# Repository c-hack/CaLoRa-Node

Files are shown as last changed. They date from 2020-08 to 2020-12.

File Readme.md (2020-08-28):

# CaLoRa-Node
## c-hack.de and surasto.de 2020 

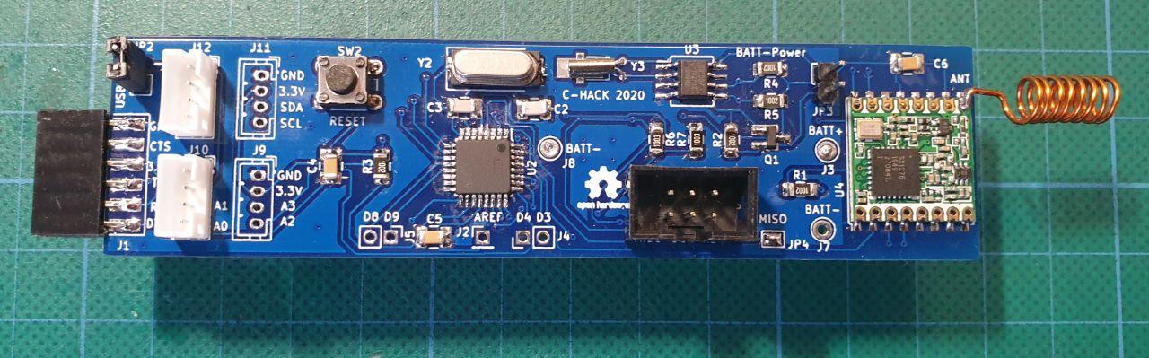
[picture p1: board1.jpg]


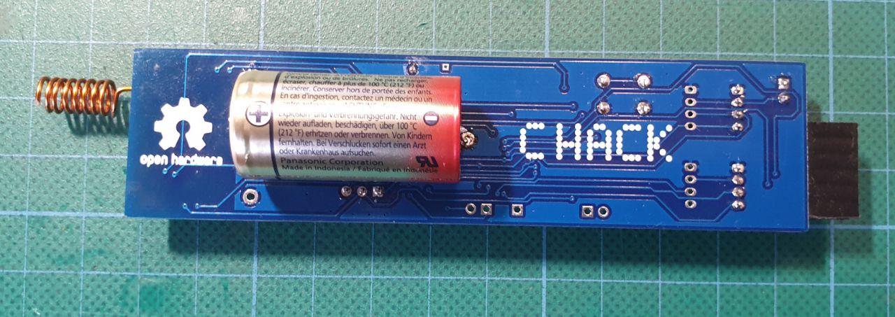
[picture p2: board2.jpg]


This LoRaWAN node is designed to run for long time on a battery.
It uses an external RTC (DS1337) with alarm function to enable or disable the complete power supply by switching a P-MOS FET.
This is the deepest sleep possible.

It uses an Atmel ATMega328 with the Arduino-UNO bootloader.
The LoRAWAN is implemented with an HopeRF RFM95W module.
The board implements some grove compatible connectors wuth I2C and analog inputs of the MCU.

We use the [lmic](https://github.com/matthijskooijman/arduino-lmic "lmic") software library for now but will add a wrapper to make it simpler.

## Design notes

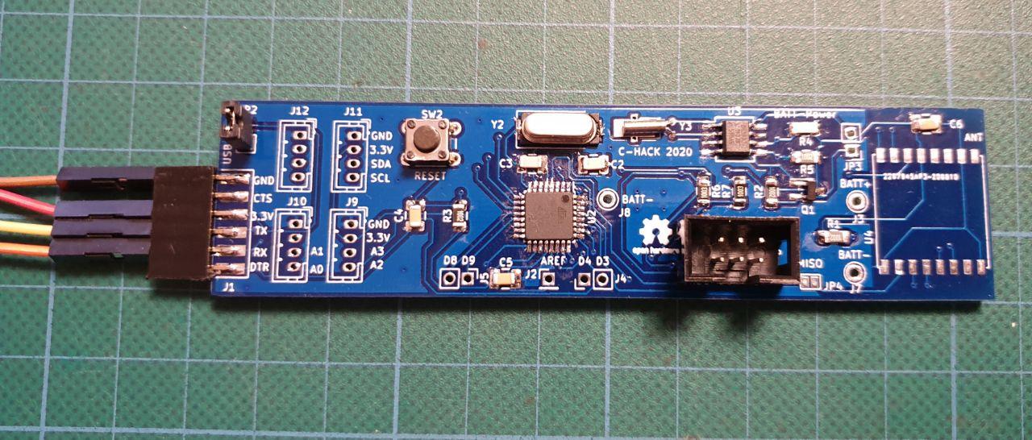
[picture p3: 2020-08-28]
board.jpg

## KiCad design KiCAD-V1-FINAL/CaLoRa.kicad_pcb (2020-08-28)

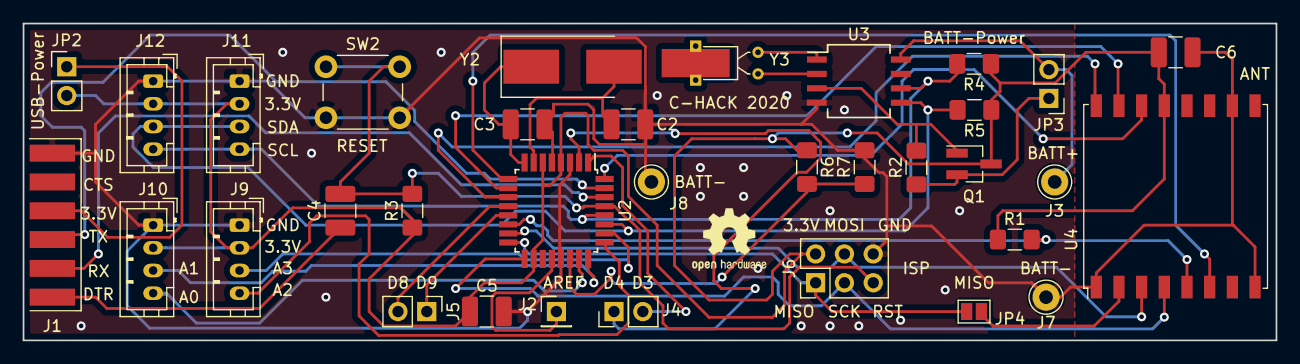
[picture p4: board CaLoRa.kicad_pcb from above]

Board: 2 copper layers, 110.5 x 27.9 mm, 34 parts (0 on the bottom side), 35 nets.

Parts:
C2, C3: 22p; C_1210_3225Metric_Pad1.42x2.65mm_HandSolder
C4, C5, C6: 100n; C_1210_3225Metric_Pad1.42x2.65mm_HandSolder
J1: Conn_01x06_Male; TestPoint_Pad_6x1.5x4.0mm
J2: Conn_01x01_Male; PinHeader_1x01_P2.54mm_Vertical
J3, J7, J8: Screw_Terminal_01x01; Pin_D1.0mm_L10.0mm_LooseFit
J4, J5: Conn_01x02_Male; PinHeader_1x02_P2.54mm_Vertical
J6: AVR-ISP-6; PinHeader_2x03_P2.54mm_Vertical
J9, J10, J11, J12: Conn_01x04_Male; JST_PH_B4B-PH-K_1x04_P2.00mm_Vertical
JP2, JP3: Jumper; PinHeader_1x02_P2.54mm_Vertical
JP4: SolderJumper_2_Open; SolderJumper-2_P1.3mm_Open_Pad1.0x1.5mm
Q1: Q_PMOS_GSD; SOT-23_Handsoldering
R1, R3, R4, R5: 10k; R_1206_3216Metric_Pad1.42x1.75mm_HandSolder
R2: 22k; R_1206_3216Metric_Pad1.42x1.75mm_HandSolder
R6, R7: 100k; R_1206_3216Metric_Pad1.42x1.75mm_HandSolder
SW2: SW_Push_Dual; SW_PUSH_6mm_H5mm
U2: ATmega328-AU; TQFP-32_7x7mm_P0.8mm
U3: DS1337; SO-8_5.3x6.2mm_P1.27mm
U4: RFM95W-868S2; HOPERF_RFM9XW_SMD
Y2: 16MHz; Crystal_SMD_7050-2Pin_7.0x5.0mm_HandSoldering
Y3: 32kHz; Crystal_DS26_D2.0mm_L6.0mm_Horizontal_1EP_style2

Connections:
+3V3: C5.1, C6.1, J6.2, J9.2, J10.2, J11.2, J12.2, JP2.2, Q1.3, R1.1, R3.1, R4.1, R5.1, R6.1, U2.4, U2.6, U2.18, U4.13
+BATT: J3.1, JP3.2, U3.8
A0: J10.4, U2.23
A1: J10.3, U2.24
A2: J9.4, U2.25
A3: J9.3, U2.26
DTR: C4.1, J1.1
GND: C2.2, C3.1, C5.2, C6.2, J1.6, J6.6, J7.1, J8.1, J9.1, J10.1, J11.1, J12.1, R7.2, SW2.2, U2.3, U2.5, U2.21, U3.4, U4.1, U4.8, U4.10
MISO: J6.1, JP4.1, U2.16
MOSI: J6.4, U2.15, U4.3
unnamed: C2.1, U2.7, Y2.2
unnamed: C3.2, U2.8, Y2.1
unnamed: C4.2, J6.5, R3.2, SW2.1, U2.29
unnamed: J1.4, JP2.1
unnamed: J2.1, U2.20
unnamed: J4.1, U2.2
unnamed: J4.2, U2.1
unnamed: J5.1, U2.13
unnamed: J5.2, U2.12
unnamed: JP3.1, Q1.2, R2.1
unnamed: JP4.2, U4.2
unnamed: Q1.1, R2.2, U3.3
unnamed: R6.2, R7.1, U2.22
unnamed: U2.9, U4.6
unnamed: U2.10, U4.15
unnamed: U2.11, U4.16
unnamed: U2.32, U4.14
unnamed: U3.1, Y3.1
unnamed: U3.2, Y3.2
RX: J1.2, U2.30
SCK: J6.3, U2.17, U4.4
SCL: J11.4, J12.4, R4.2, U2.28, U3.6
SDA: J11.3, J12.3, R5.2, U2.27, U3.5
SS: R1.2, U2.14, U4.5
TX: J1.3, U2.31

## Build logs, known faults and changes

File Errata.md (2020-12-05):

CaLoRa-Node Rev. 1
==================

Revision 1 is fully functional but a few mistakes have made it into the Schematics and the PCB:

* R7 needs to by 10kOhm (the Schematics shows 100k)  - Otherwise the VBatt measurement will not work
* The pads of the DS1337 (U3) are too wide for the package. This is OK for handsoldering but will probably not work for reflow soldering
* The silkscreen for the four JST connectors (J9..12) is turned by 180 degree. The picture shows them mounted in the right direction
 
* The connector for the UART-to-USB converter was meant to be compatible to the popular module by AZDelivery. Unfortunately we connected RX with RX and TX with TX. They should be crossed. So please solder a cable where RX conncts to TX and TX to RX. We will fix that with a future rev of the PCB.

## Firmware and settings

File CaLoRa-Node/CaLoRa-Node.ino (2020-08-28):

/*******************************************************************************
 * Copyright (c) 2015 Thomas Telkamp and Matthijs Kooijman
 *
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
 *******************************************************************************/

#include <lmic.h>
#include <hal/hal.h>
#include <SPI.h>
#include <Wire.h>
#include <DS1337.h>

static const PROGMEM u1_t NWKSKEY[16] = { 0xE0, 0x54, 0x46, 0xFC, 0x09, 0x8C, 0x4A, 0x2C, 0xF7, 0x8D, 0x83, 0x1E, 0x8C, 0xA4, 0xE0, 0xF3 };
static const u1_t PROGMEM APPSKEY[16] = { 0x40, 0x9B, 0xD7, 0xAD, 0xE3, 0x4A, 0x24, 0x8D, 0xD5, 0x96, 0x75, 0x52, 0xC9, 0xBE, 0xE4, 0xDD };

// LoRaWAN end-device address (DevAddr)
static const u4_t DEVADDR = 0x26011AFF ; // <-- Change this address for every node!

// These callbacks are only used in over-the-air activation, so they are
// left empty here (we cannot leave them out completely unless
// DISABLE_JOIN is set in config.h, otherwise the linker will complain).
void os_getArtEui (u1_t* buf) { }
void os_getDevEui (u1_t* buf) { }
void os_getDevKey (u1_t* buf) { }

static uint8_t mydata[] = "ABCDEFabcdef";
static osjob_t sendjob;

// Schedule TX every this many seconds (might become longer due to duty
// cycle limitations).
const unsigned TX_INTERVAL = 60;

// Pin mapping
const lmic_pinmap lmic_pins = {
    .nss = 10,
    .rxtx = LMIC_UNUSED_PIN,
    .rst = 9,
    .dio = {2, 6, 7},
};

void onEvent (ev_t ev) {
    Serial.print(os_getTime());
    Serial.print(": ");
    switch(ev) {
        case EV_SCAN_TIMEOUT:
            Serial.println(F("EV_SCAN_TIMEOUT"));
            break;
        case EV_BEACON_FOUND:
            Serial.println(F("EV_BEACON_FOUND"));
            break;
        case EV_BEACON_MISSED:
            Serial.println(F("EV_BEACON_MISSED"));
            break;
        case EV_BEACON_TRACKED:
            Serial.println(F("EV_BEACON_TRACKED"));
            break;
        case EV_JOINING:
            Serial.println(F("EV_JOINING"));
            break;
        case EV_JOINED:
            Serial.println(F("EV_JOINED"));
            break;
        case EV_RFU1:
            Serial.println(F("EV_RFU1"));
            break;
        case EV_JOIN_FAILED:
            Serial.println(F("EV_JOIN_FAILED"));
            break;
        case EV_REJOIN_FAILED:
            Serial.println(F("EV_REJOIN_FAILED"));
            break;
        case EV_TXCOMPLETE:
            Serial.println(F("EV_TXCOMPLETE (includes waiting for RX windows)"));
            if (LMIC.txrxFlags & TXRX_ACK)
              Serial.println(F("Received ack"));
            if (LMIC.dataLen) {
              Serial.println(F("Received "));
              Serial.println(LMIC.dataLen);
              Serial.println(F(" bytes of payload"));
              for (int i=0; i<LMIC.dataLen; i++) Serial.print(LMIC.frame[LMIC.dataBeg+i]);
            }
            // Schedule next transmission
            os_setTimedCallback(&sendjob, os_getTime()+sec2osticks(TX_INTERVAL), do_send);
            break;
        case EV_LOST_TSYNC:
            Serial.println(F("EV_LOST_TSYNC"));
            break;
        case EV_RESET:
            Serial.println(F("EV_RESET"));
            break;
        case EV_RXCOMPLETE:
            // data received in ping slot
            Serial.println(F("EV_RXCOMPLETE"));
            break;
        case EV_LINK_DEAD:
            Serial.println(F("EV_LINK_DEAD"));
            break;
        case EV_LINK_ALIVE:
            Serial.println(F("EV_LINK_ALIVE"));
            break;
         default:
            Serial.println(F("Unknown event"));
            break;
    }
}

void do_send(osjob_t* j){
    // Check if there is not a current TX/RX job running
    if (LMIC.opmode & OP_TXRXPEND) {
        Serial.println(F("OP_TXRXPEND, not sending"));
    } else {
        // Prepare upstream data transmission at the next possible time.
        LMIC_setTxData2(1, mydata, sizeof(mydata)-1, 0);
        Serial.println(F("Packet queued"));
    }
    // Next TX is scheduled after TX_COMPLETE event.
}

// Sets the RTC DS1337 to 12:00 and adds hours and minutes for the Alarm time
// Then the Alrm gets cleard so that the whole circuit shuts off
void gotoSleep(int hours, int minutes) {
  DS1337 rtc;
  Date d;
  
  rtc.init();
  rtc.setTime(12,0);
  rtc.setAlarmMode(DS1337_ALARM_ON_SECOND_MINUTE_HOUR);
  rtc.setAlarm(12+hours, minutes, 0);

  d= rtc.getDate();
  Serial.println("Time and Date ="+d.getTimeString());

  d = rtc.getAlarm();
  Serial.println("Alarm ="+d.getTimeString());

  
  rtc.enableAlarm();
  rtc.clearAlarm();

}

void setup() {
    Serial.begin(115200);
    Serial.println(F("Starting"));
    Serial.print("Debug Level = ");
    Serial.println(LMIC_DEBUG_LEVEL);

    // LMIC init
    os_init();
    // Reset the MAC state. Session and pending data transfers will be discarded.
    LMIC_reset();

    // Set static session parameters. Instead of dynamically establishing a session
    // by joining the network, precomputed session parameters are be provided.
    #ifdef PROGMEM
    // On AVR, these values are stored in flash and only copied to RAM
    // once. Copy them to a temporary buffer here, LMIC_setSession will
    // copy them into a buffer of its own again.
    uint8_t appskey[sizeof(APPSKEY)];
    uint8_t nwkskey[sizeof(NWKSKEY)];
    memcpy_P(appskey, APPSKEY, sizeof(APPSKEY));
    memcpy_P(nwkskey, NWKSKEY, sizeof(NWKSKEY));
    LMIC_setSession (0x1, DEVADDR, nwkskey, appskey);
    #else
    // If not running an AVR with PROGMEM, just use the arrays directly
    LMIC_setSession (0x1, DEVADDR, NWKSKEY, APPSKEY);
    #endif

    #if defined(CFG_eu868)
    // Set up the channels used by the Things Network, which corresponds
    // to the defaults of most gateways. Without this, only three base
    // channels from the LoRaWAN specification are used, which certainly
    // works, so it is good for debugging, but can overload those
    // frequencies, so be sure to configure the full frequency range of
    // your network here (unless your network autoconfigures them).
    // Setting up channels should happen after LMIC_setSession, as that
    // configures the minimal channel set.
    LMIC_setupChannel(0, 868100000, DR_RANGE_MAP(DR_SF12, DR_SF7),  BAND_CENTI);      // g-band
    LMIC_setupChannel(1, 868300000, DR_RANGE_MAP(DR_SF12, DR_SF7B), BAND_CENTI);      // g-band
    LMIC_setupChannel(2, 868500000, DR_RANGE_MAP(DR_SF12, DR_SF7),  BAND_CENTI);      // g-band
    LMIC_setupChannel(3, 867100000, DR_RANGE_MAP(DR_SF12, DR_SF7),  BAND_CENTI);      // g-band
    LMIC_setupChannel(4, 867300000, DR_RANGE_MAP(DR_SF12, DR_SF7),  BAND_CENTI);      // g-band
    LMIC_setupChannel(5, 867500000, DR_RANGE_MAP(DR_SF12, DR_SF7),  BAND_CENTI);      // g-band
    LMIC_setupChannel(6, 867700000, DR_RANGE_MAP(DR_SF12, DR_SF7),  BAND_CENTI);      // g-band
    LMIC_setupChannel(7, 867900000, DR_RANGE_MAP(DR_SF12, DR_SF7),  BAND_CENTI);      // g-band
    LMIC_setupChannel(8, 868800000, DR_RANGE_MAP(DR_FSK,  DR_FSK),  BAND_MILLI);      // g2-band
    #endif

    // Let LMIC compensate for +/- 1% clock error
    LMIC_setClockError(MAX_CLOCK_ERROR * 1 / 100);

    // Disable link check validation
    LMIC_setLinkCheckMode(0);

    // TTN uses SF9 for its RX2 window.
    LMIC.dn2Dr = DR_SF9;

    // Set data rate and transmit power for uplink (note: txpow seems to be ignored by the library)
    LMIC_setDrTxpow(DR_SF7,14);

    // Start job
    do_send(&sendjob);

    delay(10000);

    gotoSleep(0,1);   // 0 Houres, 1 Minute Sleep time
}


// ======= Dieser Code wird nur im Debug-Mode erreicht, wenn die Schaltung am USB-Port betrieben wird ====================
void loop() {
  DS1337 rtc;
  Date d;
  String status;

  d= rtc.getDate();
  Serial.print("Time and Date = "+d.getTimeString());
  if (rtc.isAlarmEnabled()) status = "Ja"; else status = "Nein";
  Serial.print(" Alarm Enabled = "+status);
  if (rtc.isAlarmActive()) status = "Ja"; else status = "Nein";
  Serial.println(" Alarm on = "+ status);

  os_runloop_once();
  
  delay(5000);
    
}
